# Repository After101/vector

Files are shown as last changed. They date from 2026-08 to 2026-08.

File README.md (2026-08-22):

# vector

  This is a custom wearable I'm working on that uses the nRF52840 featuring:
  - BLE
  - Gesture based controls
  - ST7789 raw OLED panel
  - Haptic feedback
  - Custom enclosure
  - Magnetic pogo pin charging and programming
  -  29mm x 20mm PCB 
  -  Enclosure WIP

  Current status:
  - PCB complete
  - Enclosure WIP
  - Firmware not done yet

  This is a revision of my previous project lol
  
  Images:
  
  4 layer PCB finally
  
  


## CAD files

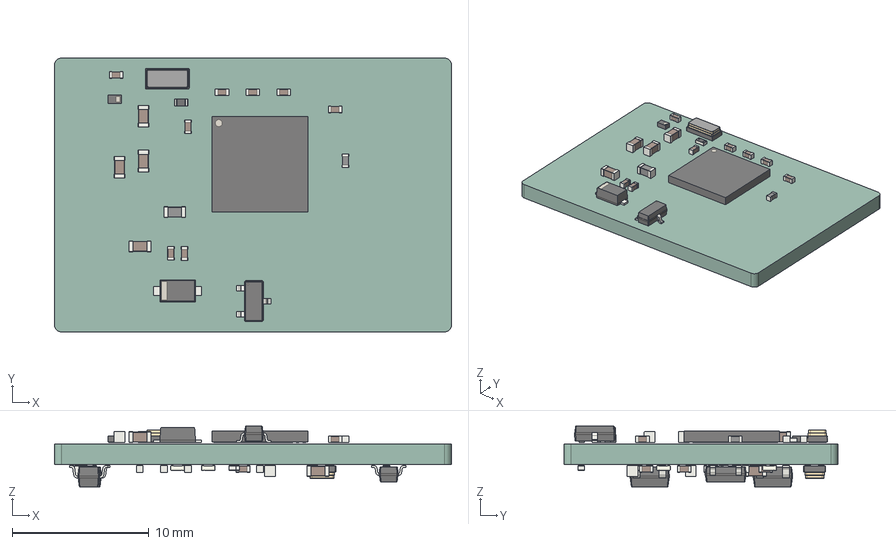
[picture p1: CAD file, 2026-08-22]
watch_v2.step
29.0 x 20.0 x 4.43 mm
C_0603_1608Metric x 8
L_0402_1005Metric x 2
L_0603_1608Metric
C_0402_1005Metric x 16
D_SOD-882
D_SOD-123F
R_0402_1005Metric x 8
Crystal_SMD_3215-2Pin_3.2x1.5mm
Nordic_AQFN-73-1EP_7x7mm_P0.5mm
SOT-23 x 2
Crystal_SMD_2016-4Pin_2.0x1.6mm
SOT-23-5 x 2
watch_v2_PCB

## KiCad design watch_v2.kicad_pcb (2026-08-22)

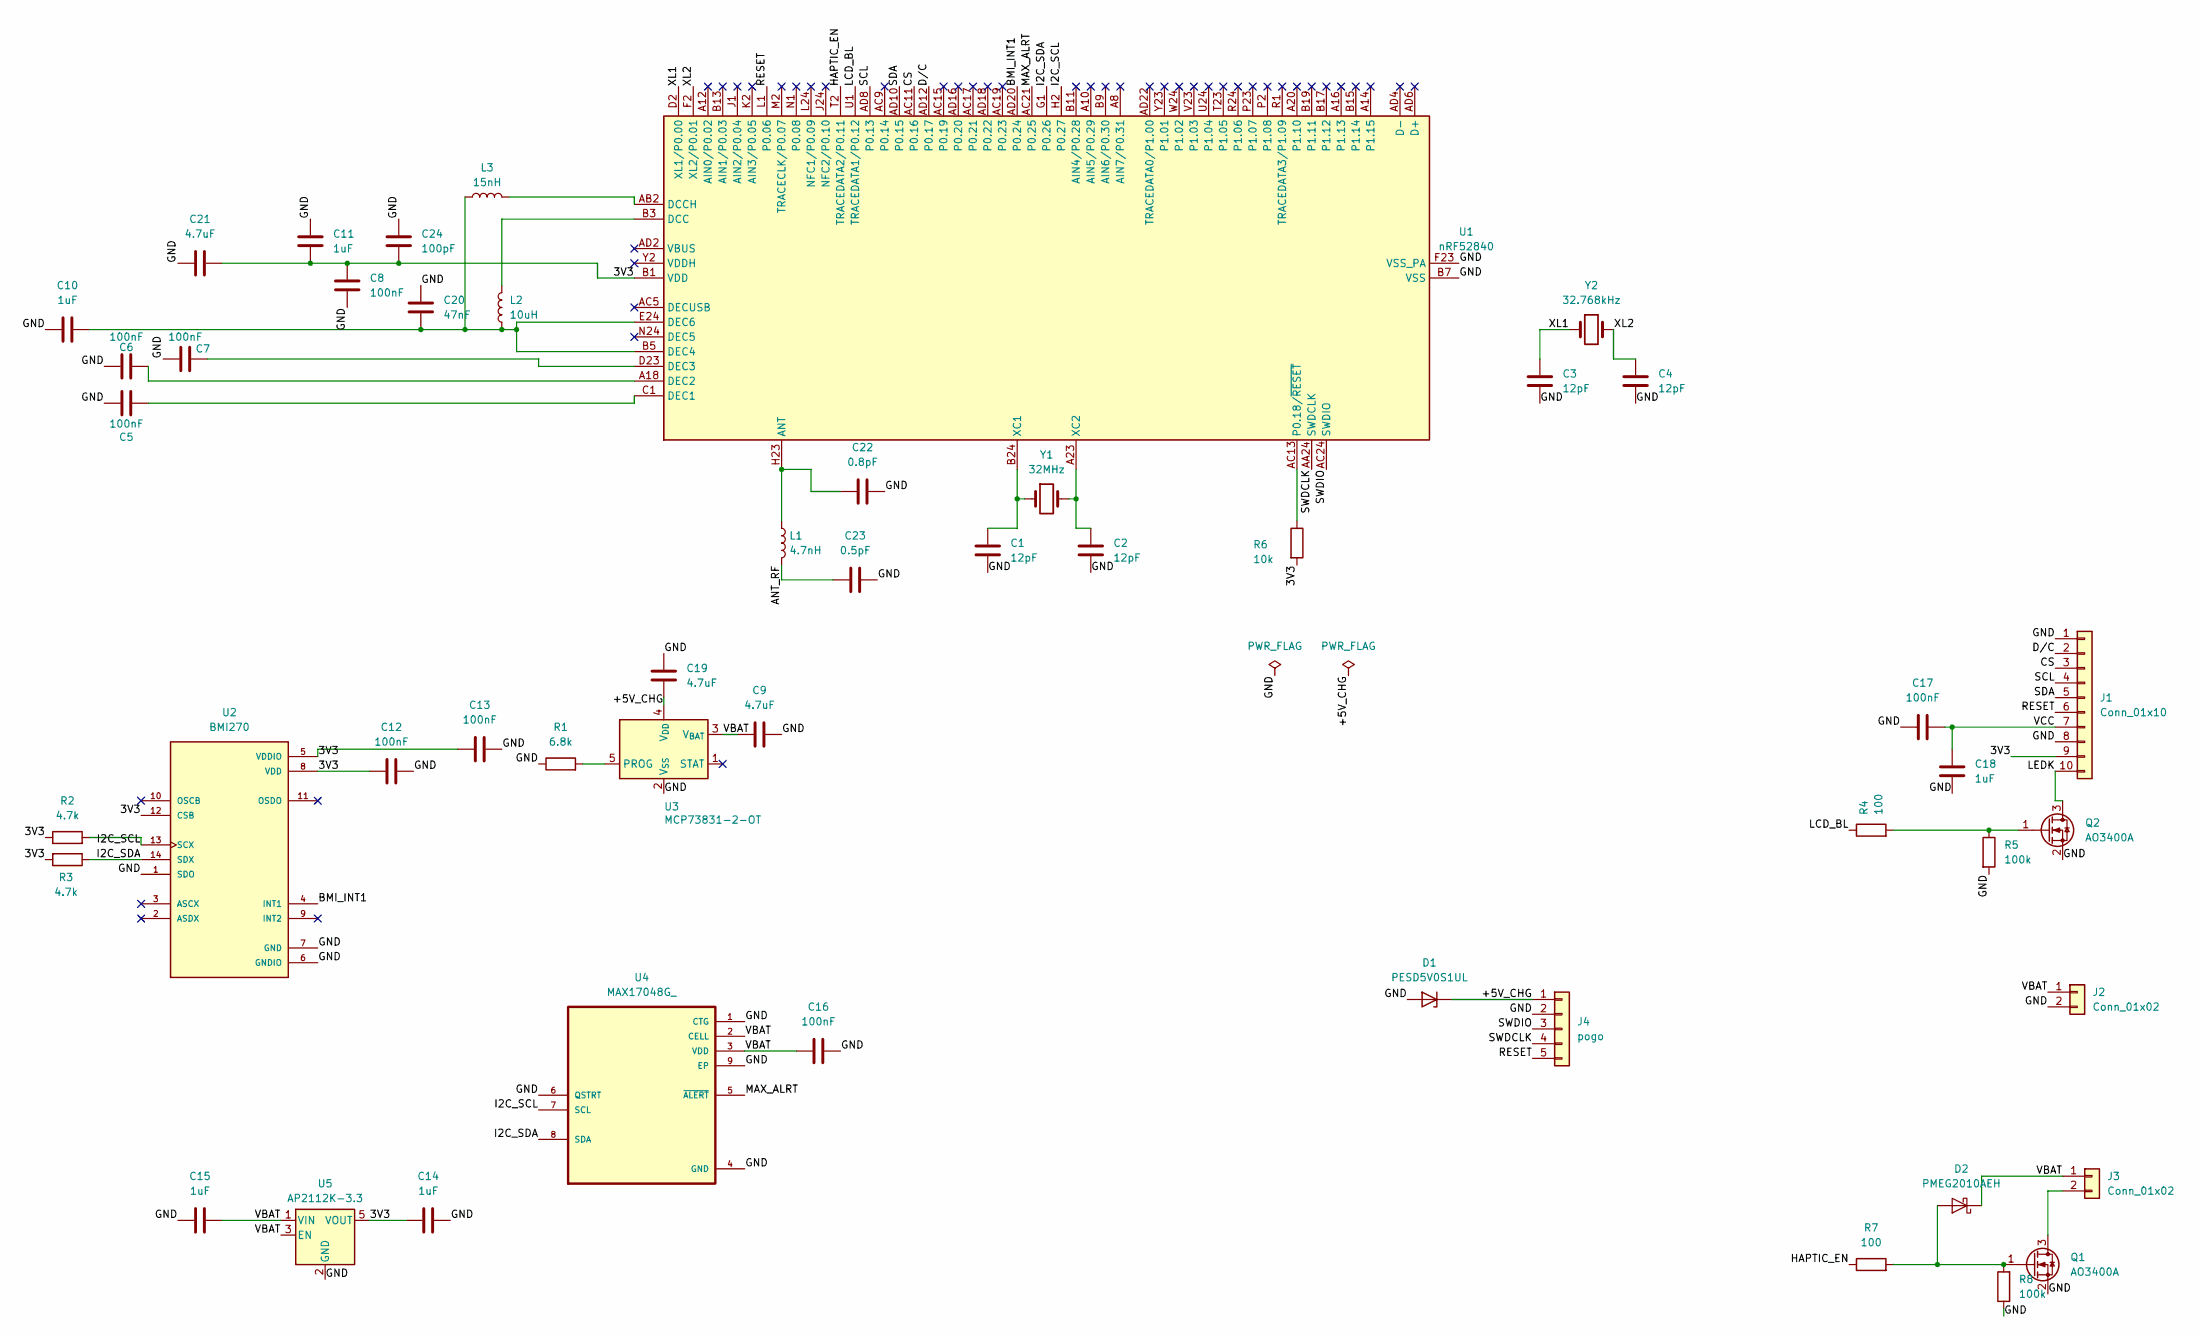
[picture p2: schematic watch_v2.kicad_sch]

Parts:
C1, C2, C3, C4: 12pF; C_0402_1005Metric
C5, C6, C7, C8, C12, C13, C16, C17: 100nF; C_0402_1005Metric
C9, C19, C21: 4.7uF; C_0603_1608Metric
C10, C11, C14, C15, C18: 1uF; C_0603_1608Metric
C20: 47nF; C_0402_1005Metric
C22: 0.8pF; C_0402_1005Metric
C23: 0.5pF; C_0402_1005Metric
C24: 100pF; C_0402_1005Metric
D1: PESD5V0S1UL; D_SOD-882
D2: PMEG2010AEH; D_SOD-123F
J1: Conn_01x10; Amphenol_F32Q-1A7x1-11010_1x10-1MP_P0.5mm_Horizontal
J2, J3: Conn_01x02; BATTERY_2P_SOLDER
J4: pogo; pogo pin
L1: 4.7nH; L_0402_1005Metric
L2: 10uH; L_0603_1608Metric
L3: 15nH; L_0402_1005Metric
Q1, Q2: AO3400A; SOT-23
R1: 6.8k; R_0402_1005Metric
R2, R3: 4.7k; R_0402_1005Metric
R4, R7: 100; R_0402_1005Metric
R5, R8: 100k; R_0402_1005Metric
R6: 10k; R_0402_1005Metric
U1: nRF52840; Nordic_AQFN-73-1EP_7x7mm_P0.5mm
U2: BMI270; XDCR_BMI270
U3: MCP73831-2-OT; SOT-23-5
U4: MAX17048G_; SON50P200X200X80-9N
U5: AP2112K-3.3; SOT-23-5
Y1: 32MHz; Crystal_SMD_2016-4Pin_2.0x1.6mm
Y2: 32.768kHz; Crystal_SMD_3215-2Pin_3.2x1.5mm

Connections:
/3V3: C8.2, C11.2, C12.1, C13.1, C14.1, C21.2, C24.2, J1.9, R2.1, R3.2, R6.2, U1.A22 (VDD), U1.AD14 (VDD), U1.AD23 (VDD), U1.B1 (VDD), U1.W1 (VDD), U2.5 (VDDIO), U2.8 (VDD), U2.12 (CSB), U5.5 (VOUT)
/+5V_CHG: C19.1, D1.1 (K), J4.1, U3.4 (V_{DD})
/ANT_RF: C23.1, L1.2
/BMI_INT1: U1.AD20 (P0.24), U2.4 (INT1)
/CS: J1.3, U1.AC11 (P0.16)
/D/C: J1.2, U1.AD12 (P0.17)
/GND: C1.2, C2.2, C3.2, C4.2, C5.1, C6.1, C7.1, C8.1, C9.2, C10.1, C11.1, C12.2, C13.2, C14.2, C15.1, C16.2, C17.1, C18.1, C19.2, C20.1, C21.1, C22.2, C23.2, C24.1, D1.2 (A), J1.1, J1.8, J2.2, J4.2, Q1.2 (S), Q2.2 (S), R1.1, R5.2, R8.1, U1.B7 (VSS), U1.EP (VSS), U1.F23 (VSS_PA), U2.1 (SDO), U2.6 (GNDIO), U2.7 (GND), U3.2 (V_{SS}), U4.1 (CTG), U4.4 (GND), U4.6 (QSTRT), U4.9 (EP), U5.2 (GND)
/HAPTIC_EN: R7.1, U1.T2 (TRACEDATA2/P0.11)
/I2C_SCL: R2.2, U1.H2 (P0.27), U2.13 (SCX), U4.7 (SCL)
/I2C_SDA: R3.1, U1.G1 (P0.26), U2.14 (SDX), U4.8 (SDA)
/LCD_BL: R4.1, U1.U1 (TRACEDATA1/P0.12)
/LEDK: J1.10, Q2.3 (D)
/MAX_ALRT: U1.AC21 (P0.25), U4.5 (~ALERT)
/RESET: J1.6, J4.5, U1.L1 (P0.06)
/SCL: J1.4, U1.AD8 (P0.13)
/SDA: J1.5, U1.AD10 (P0.15)
/SWDCLK: J4.4, U1.AA24 (SWDCLK)
/SWDIO: J4.3, U1.AC24 (SWDIO)
/VBAT: C9.1, C15.2, C16.1, D2.1 (K), J2.1, J3.1, U3.3 (V_{BAT}), U4.2 (CELL), U4.3 (VDD), U5.1 (VIN), U5.3 (EN)
/VCC: C17.2, C18.2, J1.7
/XL1: C3.1, U1.D2 (XL1/P0.00), Y2.1
/XL2: C4.1, U1.F2 (XL2/P0.01), Y2.2
unnamed: D2.2 (A), Q1.1 (G), R7.2, R8.2
unnamed: J3.2, Q1.3 (D)
unnamed: Q2.1 (G), R4.2, R5.1
unnamed: C22.1, L1.1, U1.H23 (ANT)
unnamed: L2.2, U1.B3 (DCC)
unnamed: L3.2, U1.AB2 (DCCH)
unnamed: C5.2, U1.C1 (DEC1)
unnamed: C6.2, U1.A18 (DEC2)
unnamed: C7.2, U1.D23 (DEC3)
unnamed: C10.2, C20.2, L2.1, L3.1, U1.B5 (DEC4), U1.E24 (DEC6)
unnamed: R6.1, U1.AC13 (P0.18/~RESET)
unnamed: C1.1, U1.B24 (XC1), Y1.1
unnamed: C2.1, U1.A23 (XC2), Y1.2
unnamed: R1.2, U3.5 (PROG)

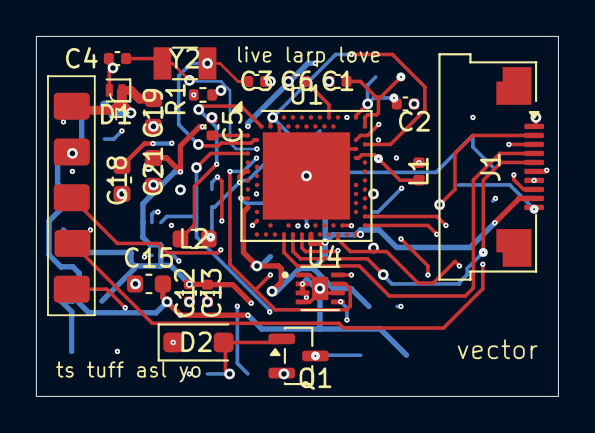
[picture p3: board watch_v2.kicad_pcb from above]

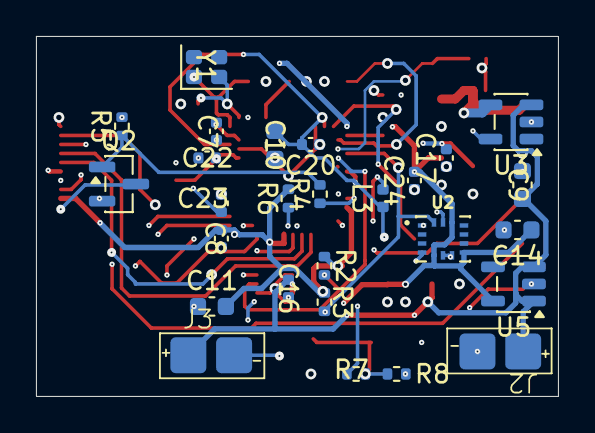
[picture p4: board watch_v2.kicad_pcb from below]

Board: 4 copper layers, 29.0 x 20.0 mm, 50 parts (27 on the bottom side), 36 nets.

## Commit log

2026-07-10 Fix formatting in README for current status section
2026-08-22 Revise project details in README.md
    Updated project details including display type, charging method, and enclosure status.
2026-08-22 Add images to README for project visualization
    Added images to the README to showcase the PCB and a screenshot.
